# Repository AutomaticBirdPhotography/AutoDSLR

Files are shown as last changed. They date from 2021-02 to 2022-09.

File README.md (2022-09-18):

# AutoDSLR
Tracking pan-tilt DSLR head

På remote:  
```
sudo pip3 install -r requirements.txt
sudo pip3 install -U vidgear[core]
sudo apt install libgraphite2-3 libatspi2.0-0 libthai0 libxcb-shm0 libxcb-render0 libswscale5 librsvg2-2 libvorbisenc2 libavutil56 libzvbi0 libgsm1 libxinerama1 libxvidcore4 libsrt1.4-gnutls libswresample3 libatk1.0-0 libvorbisfile3 libogg0 libpangoft2-1.0-0 libpgm-5.3-0 libwayland-egl1 libharfbuzz0b libpango-1.0-0 libcairo2 libva-x11-2 libwayland-cursor0 libgfortran5 libxfixes3 libgme0 libxrender1 libvorbis0a libxi6 libudfread0 libspeex1 libwebpmux3 libsodium23 libdatrie1 libatk-bridge2.0-0 libxrandr2 libbluray2 libx264-160 libwavpack1 libxcomposite1 libpangocairo-1.0-0 libsoxr0 libshine3 libxkbcommon0 libvdpau1 libgtk-3-0 libopus0 librabbitmq4 libgdk-pixbuf-2.0-0 libavformat58 libmpg123-0 libxdamage1 libzmq5 libdav1d4 libopenmpt0 libatlas3-base libva2 libva-drm2 libxcursor1 libssh-gcrypt-4 libavcodec58 libaom0 libx265-192 libwayland-client0 libcairo-gobject2 libcodec2-0.9 libpixman-1-0 libdrm2 libsnappy1v5 libnorm1 libopenjp2-7 libtheora0 ocl-icd-libopencl1 libtwolame0 libvpx6 libepoxy0 libchromaprint1 libmp3lame0

#sudo apt-get install libatlas-base-dev libhdf5-dev libhdf5-serial-dev libatlas-base-dev libjasper-dev -y

cd /usr/share/applications
sudo cp python3.9.desktop remote.desktop
sudo nano remote.desktop
[Desktop Entry]
Encoding=UTF-8
Type=Application
Name=PanTilt Remote
Icon=/home/pi/Documents/AutoDSLR-main/icon.png
Terminal=true
Exec=/usr/bin/python3.9 /home/pi/Documents/AutoDSLR-main/pan_tilt_remote_v2.py
StartupNotify=false
Categories=Other

sudo cp remote.desktop shutdown.desktop
sudo nano shutdown.desktop
[Desktop Entry]
Encoding=UTF-8
Type=Application
Name=Shutdown
Icon=/home/pi/Documents/AutoDSLR-main/shutdown.png
Terminal=true
Exec=/usr/bin/python3.9 /home/pi/Documents/AutoDSLR-main/shutdown.py
StartupNotify=false
Categories=Other

cd /usr/local/lib/python3.9/dist-packages/vidgear/gears
sudo nano netgear.py
ctrl+"-"
681
endre fra 96 til 1
ctrl+"x"
y
enter

```

Problemer:

Koden for remote er egt. utdatert. Noe feil med "ved klikk" 10x for mye eller noe

Sliter med å få lock ved tracking

Krasjer med error "Broken pipe" stadig

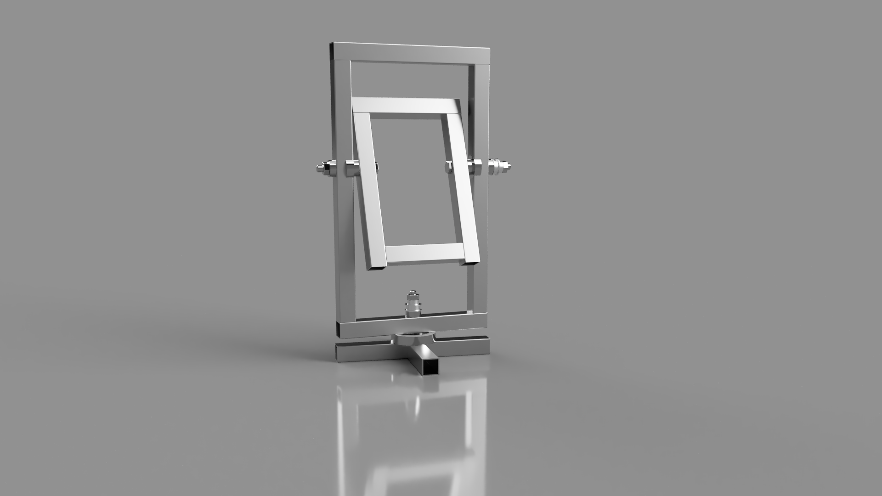
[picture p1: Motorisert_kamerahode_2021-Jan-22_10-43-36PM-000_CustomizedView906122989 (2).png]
The head


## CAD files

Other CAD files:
PCB_PanTilt v13.f3z
Pan tilt utstyrsboks v13.f3d

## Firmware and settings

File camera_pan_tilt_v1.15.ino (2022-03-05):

/*
      Author: Robert

      Version: 1.15.13
      Notes:
      Versjon 11 - Totalt endret hvordan stativet kjører; positiv y verdi kjører opp, positiv x verdi kjører høyre:
              0,10
               |
               |
      -10,0---0,0---10,0
               |
               |
              0,-10
      Data ved vanlig kjøring typ. joy: x, y, servo_x, servo_y
      Ved til point: p x_grader, y_grader

      Versjon 12 - Totalt endret hvordan servoen styrer etter data. Legger til grader hvert x millisekund, ettersom dette er det det ville blitt sendt på med python tidligere.
                .10 - satt tilbake hvordan servoen kan komme tilbake etter overstyring
                .13 - bevegelse i stativet etter "til klikk" løst ved å sette: innkommende = "0,0,0,0"
                .14 - endret hastigheten på servoen, sendes nå i verdier opp til 10
                .15 - lagt til pan og tilt offset for å kalibrere servokamera mot speilrefleks
                .17 - tune verdier ved align
      Versjon 1.xx - Med enablepins til motorene, potentiometer for initiell posisjon
                12
                  .01 - "b" skendes for å endre enable-pin, "f" for enable fokus
                13 - smoothing ved v- og hSpeed
                14 - servoer går til hjem rolig
                  .1 - med sending av steps
                15 - total endret hvordan enablepins fungerer, dette for å unngå "fantomtelling" av steps


      Python: pantilt.py -på stativet
*/
#include <Servo.h>
Servo panServo;
Servo tiltServo;
float posTilt = 0;
float posPan = 0;
float pan_offset = 12; //verdiene er etter de på kartet, negativ er venstre
float tilt_offset = -6; //negative verdier vil få den til å gå gå mot positive verdier
float OldPosTilt = 90 + tilt_offset;
float OldPosPan = 90 + pan_offset;
int tiltLimit = 85;
int i = 1;
int n = 1;
int gjenMove = 0;
unsigned long timeNow = 0;
int period = 90; //oppdateringsfrekvensen på servoen

#include <AccelStepper.h>

const int vertikalDirPin = 7;
const int vertikalStepPin = 6;
const int enablePin = 2;
String vIn = "0";
String OvIn = "0";
int vSpeed = 0;
float vSpeedSmooth = 0;
float vSpeedPrev = 0;   //brukes for smoothing
int vPosPrev = 0;      //brukes for sending av steps til serial
#define motorInterfaceType 1
AccelStepper vertikal(motorInterfaceType, vertikalStepPin, vertikalDirPin);

const int horisontalDirPin = 8;
const int horisontalStepPin = 9;
String hIn = "0";
String OhIn = "0";
int hSpeed = 0;
float hSpeedSmooth = 0;
float hSpeedPrev = 0;   //brukes for smoothing
int hPosPrev = 0;      //brukes for sending av steps til serial
#define motorInterfaceType 1
AccelStepper horisontal(motorInterfaceType, horisontalStepPin, horisontalDirPin);

const int fokusEnablePin = 12;
/*
  const int fokusDirPin = 3;
  const int fokusStepPin = 4;

  String fIn = "0";
  String OfIn = "0";
  int fSpeed = 0;
  #define motorInterfaceType 1
  AccelStepper fokus(motorInterfaceType, fokusStepPin, fokusDirPin);
*/
const int maxUp = 650;
const int maxDown = -350;       //hvor langt motoren kan gå før det er fare for at kameraet treffer rammen
String innkommende;
bool enable = false;
bool fokusEnable = false;

#define pot A7
unsigned long potVerdi = 0;

void setup() {
  pinMode(pot, INPUT);

  digitalWrite(fokusEnablePin, HIGH);

  panServo.attach(11);
  tiltServo.attach(10);
  panServo.write(90 + pan_offset);
  tiltServo.write(90 + tilt_offset);



  vertikal.setMaxSpeed(200);
  vertikal.setCurrentPosition(0);
  vertikal.setAcceleration(5000);
  vertikal.setEnablePin(enablePin);
  vertikal.setPinsInverted(false, false, true);   //enable når pinnen er LOW
  horisontal.setMaxSpeed(200);
  horisontal.setAcceleration(5000);
  horisontal.setCurrentPosition(0);
  horisontal.setEnablePin(enablePin);
  horisontal.setPinsInverted(false, false, true);
  //fokus.setMaxSpeed(100);
  //fokus.setAcceleration(300);
  //fokus.setCurrentPosition(0);
  Serial.begin(115200);
  Serial.setTimeout(15);

  //skrur seg på, så kjører til hjem
  vertikal.enableOutputs();     //vertikal og horisontal har samme enablepin; så ubetydelig hvem som er valgt
  for (int i = 0; i < 500; i++) {
    potVerdi += analogRead(pot);
  }
  int homing = map((potVerdi / 500), 838, 596, 500, -500); //verdier kalibrert tidligere
  potVerdi = 0;
  vertikal.setSpeed(50);
  vertikal.move(homing);
  vertikal.runToPosition();
  vertikal.setCurrentPosition(0);
  vertikal.setSpeed(200);
  vertikal.disableOutputs();
  // motorene skal ikke være på i starten

}

void loop() {
  if (Serial.available() > 0) {
    innkommende = Serial.readStringUntil('\n');
  }
  if (innkommende[0] != 'h' && innkommende[0] != 'a' && innkommende[0] != 'p' && innkommende[0] != 'b' && innkommende[0] != 'f') {  //må ikke være noen av disse verdiene
    int komma = innkommende.indexOf(',');
    int andrekomma = innkommende.indexOf(',', komma + 1);
    int tredjekomma = innkommende.indexOf(',', andrekomma + 1);
    int fjerdekomma = innkommende.indexOf(',', tredjekomma + 1);
    String hIn = innkommende.substring(0, komma);
    String vIn = innkommende.substring(komma + 1, andrekomma);
    String AxisPan = innkommende.substring(andrekomma + 1, tredjekomma);
    String AxisTilt = innkommende.substring(tredjekomma + 1, fjerdekomma);
    float posTilt = AxisTilt.toFloat() / -10;
    if (posTilt < 8.0/-10.0) posTilt = 8.0/-10.0;           //må endres i samsvar med kontroller (-10.0 (.0 for float) må endres etter hva man deler på ved Axis-), forhindrer feildata!
    else if (posTilt > 8.0/10.0) posTilt = 8.0/10.0;
    
    float posPan = AxisPan.toFloat() / -10;
    if (posPan < 8.0/-10.0) posPan = 8.0/-10.0;
    else if (posPan > 8.0/10.0) posPan = 8.0/10.0;

    if (millis() >= timeNow + period) {
      timeNow = millis();
      panServo.write(OldPosPan + posPan);
      if (OldPosPan >= 180) {
        if (posPan < 0) {
          OldPosPan += posPan;
        }
      }
      else if (OldPosPan <= 0) {
        if (posPan > 0) {
          OldPosPan += posPan;
        }
      }
      else {
        OldPosPan += posPan;
      }
      
      if (OldPosPan < 75 || OldPosPan > 115) {
        if (OldPosTilt > tiltLimit) {      //0 Er rett opp, 180 rett ned; lavere verdi: høyere opp
          tiltServo.write(tiltLimit);
          OldPosTilt = tiltLimit;
        }
        if (OldPosTilt + posTilt > tiltLimit) {
          tiltServo.write(tiltLimit);
          OldPosTilt = tiltLimit;
        }
        else {
          tiltServo.write(OldPosTilt + posTilt);
        }

      }
      else {
        tiltServo.write(OldPosTilt + posTilt);
      }

      if (OldPosTilt >= 120) {
        if (posTilt < 0) {
          OldPosTilt += posTilt;
        }
      }
      else if (OldPosTilt <= 60) {
        if (posTilt > 0) {
          OldPosTilt += posTilt;
        }
      }
      else {
        OldPosTilt += posTilt;
      }
    }
    //-----------------------------------
    if (vIn != OvIn) {
      vSpeed = -vIn.toInt();
    }

    if (hIn != OhIn) {
      hSpeed = hIn.toInt();
    }


    OhIn = hIn;
    OvIn = vIn;
  }



  if (innkommende[0] == 'h' && enable) { //skal ikke bli sann om motorene ikke er på
    if (i == 1) {
      int x = panServo.read();
      if (x < 90 + pan_offset) {
        for (int i = x; i <= 90 + pan_offset; i++) {
          panServo.write(i);
          delay(50);
        }
      }
      else if (x > 90 + pan_offset) {
        for (int i = x; i >= 90 + pan_offset; i--) {
          panServo.write(i);
          delay(50);
        }
      }

      //------tilt--
      x = tiltServo.read();
      if (x < 90 + tilt_offset) {
        for (int i = x; i <= 90 + tilt_offset; i++) {
          tiltServo.write(i);
          delay(50);
        }
      }
      else if (x > 90 + tilt_offset) {
        for (int i = x; i >= 90 + tilt_offset; i--) {
          tiltServo.write(i);
          delay(50);
        }
      }

      for (int i = 0; i < 500; i++) {
        potVerdi += analogRead(pot);
      }
      int homing = map((potVerdi / 500), 838, 596, 500, -500); //verdier kalibrert tidligere
      potVerdi = 0;
      vertikal.move(homing);
      vertikal.setSpeed(70);
      while (vertikal.distanceToGo() != 0) {
        vertikal.runSpeedToPosition();
      }
      vertikal.setCurrentPosition(0);
      i = 2;
      OldPosPan = 90 + pan_offset;
      OldPosTilt = 90 + tilt_offset;
    }
    Serial.println("h");
  }
  else if (innkommende[0] == 'a' && enable) {
    if (n == 1) {
      //nema 17 : 200 steps pr rev. *16(microstepping) *1,8(36/20(tannhjul))=5760 -> 1deg = 16steps (5760/360)
      float horisontalAlignPos = (OldPosPan - (90 + pan_offset)) * 15; //kjører litt for langt
      float vertikalAlignPos = (OldPosTilt - (90 + tilt_offset)) * 16;
      if (vertikalAlignPos > maxUp) {
        vertikalAlignPos = maxUp;
      }
      else if (vertikalAlignPos < maxDown) {
        vertikalAlignPos = maxDown;
      }

      horisontal.move(horisontalAlignPos * -1);
      int totalMove = horisontal.distanceToGo();
      gjenMove = totalMove;

      vertikal.moveTo(vertikalAlignPos);

      while ((horisontal.distanceToGo() != 0 && vertikal.distanceToGo() != 0) || (horisontal.distanceToGo() != 0 || vertikal.distanceToGo() != 0)) {
        gjenMove = horisontal.distanceToGo();
        float alignPanServo = map(gjenMove, 0, totalMove, 90 + pan_offset, OldPosPan);
        panServo.write(alignPanServo);
        horisontal.setSpeed(80);
        horisontal.runSpeedToPosition();
        vertikal.setSpeed(80);
        vertikal.runSpeedToPosition();
      }
      n = 2;
      OldPosPan = 90 + pan_offset;
      innkommende = "0,0,0,0";
      Serial.println("a");
    }
  }
  else if (innkommende[0] == 'b') {
    enable = !enable;
    if (enable) {
      vertikal.enableOutputs();
    }
    if (enable == false) {
      vertikal.disableOutputs();
    }
    innkommende = "0,0,0,0";
  }
  else if (innkommende[0] == 'f') {
    fokusEnable = !fokusEnable;
    if (fokusEnable) {
      digitalWrite(fokusEnablePin, LOW);
    }
    if (fokusEnable == false) {
      digitalWrite(fokusEnablePin, HIGH);
    }

  }
  else if (innkommende[0] == 'p' && enable) {
    innkommende.remove(0, 1); //fjerner første bokstav, som er p
    int komma = innkommende.indexOf(',');
    String hGrader = innkommende.substring(0, komma);
    //Serial.println(vGrader);
    String vGrader = innkommende.substring(komma + 1);
    float fvGrader = vGrader.toFloat();
    float fhGrader = hGrader.toFloat();
    float fvSteps = fvGrader * -16;
    float fhSteps = fhGrader * 16;
    int vSteps = round(fvSteps);
    if (vSteps + vertikal.currentPosition() > maxUp) {
      vSteps = maxUp - vertikal.currentPosition();    //hvis maxUp er 300 og currentPosition er 301 blir vSteps -1, slik at den kjører tilbake dit den skal :)
    }
    else if (vSteps + vertikal.currentPosition() < maxDown) {
      vSteps = maxDown - vertikal.currentPosition();
    }
    int hSteps = round(fhSteps);
    vertikal.move(vSteps);
    horisontal.move(hSteps);
    while ((horisontal.distanceToGo() != 0 && vertikal.distanceToGo() != 0) || (horisontal.distanceToGo() != 0 || vertikal.distanceToGo() != 0)) {
      horisontal.setSpeed(100);
      horisontal.runSpeedToPosition();
      vertikal.setSpeed(100);
      vertikal.runSpeedToPosition();
    }
    hSpeed = 0;
    vSpeed = 0;
    innkommende = "0,0,0,0";
    Serial.println("p");
  }
  else {
    if (enable) {
      vSpeedSmooth = (vSpeed * 0.005) + (vSpeedPrev * 0.995);
      vSpeedPrev = vSpeedSmooth;

      //Serial.println(vertikal.currentPosition());
      if (vertikal.currentPosition() > maxUp) {
        if (vSpeed < 0) {
          vertikal.setSpeed(vSpeedSmooth);
          vertikal.runSpeed();
        }
      }
      else if (vertikal.currentPosition() < maxDown) {
        if (vSpeed > 0) {
          vertikal.setSpeed(vSpeedSmooth);
          vertikal.runSpeed();
        }
      }
      else {
        vertikal.setSpeed(vSpeedSmooth);
        vertikal.runSpeed();
      }
      hSpeedSmooth = (hSpeed * 0.005) + (hSpeedPrev * 0.995);
      hSpeedPrev = hSpeedSmooth;
      horisontal.setSpeed(hSpeedSmooth);
      horisontal.runSpeed();
      //fokus.setSpeed(fSpeed);
      //fokus.run();
      i = 1;
      n = 1;
    }
  }
  if ((horisontal.currentPosition() != hPosPrev) || (vertikal.currentPosition() != vPosPrev)) {
    //Serial.println("c" + (String)horisontal.currentPosition() + "," + (String)vertikal.currentPosition());
    hPosPrev = horisontal.currentPosition();
    vPosPrev = vertikal.currentPosition();
  }
}

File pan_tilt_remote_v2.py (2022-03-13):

"""
!DETTE ER HOVEDVERSJONEN AV PROGRAMMET. BRUKES AV REMOTE-SHORTCUT!
versjon 2.9.7
"""

import PySimpleGUI as sg
import cv2, time, pygame, math, socket, threading
import numpy as np
from vidgear.gears import NetGear

'''
Notes:
Dataen sendes slik: 
s.send("j{"lengden på bufferen"}{:.0f},{:.0f},{:.0f},{:.0f}".format(hSpeed, vSpeed, PanServo, TiltServo).encode())
'''

#-------------------------Starte ulike resurrser--------------------------------------------------
s = socket.socket(socket.AF_INET, socket.SOCK_STREAM)
retries = 15

while s.connect_ex(("192.168.4.1", 65432)) != 0:
    print(f"Kunne ikke koble til! prøver {retries} ganger til")
    retries -= 1
    if retries <= 0:
        print("Klarte ikke etablere kontakt med PanTilt!")
        exit()
    time.sleep(5)
print("Koblet til PanTilt")

options = {
    "request_timeout": 10,
    "max_retries": 20,
}
dslrClient = NetGear("192.168.4.4", 2345, receive_mode=True, pattern = 0, **options)
camClient = NetGear("192.168.4.4", 1234, receive_mode=True, pattern = 0, **options)


pygame.init()
time.sleep(1)
joystick = pygame.joystick.Joystick(0)
joystick.init()
print("Laster...")
time.sleep(0.5)

#----------------Variabler------------------------------------------------------------------
dslrScale = 95
dslrScaleFull = 130
camScale = 145
#halverer størrelsen på bildet, graphkordinatene må dobles | bildet ganges med scale/100, kordinatene deles med scale/100
#dobler størrelsen, halverer kordinatene
dslrFrameOrig = np.full((480, 640), 255, dtype='uint8') #dslrFrame = dslrClient.recv()
dslrFrame = cv2.resize(dslrFrameOrig, (int(dslrFrameOrig.shape[1]*(dslrScale/100)), int(dslrFrameOrig.shape[0]*(dslrScale/100))), interpolation = cv2.INTER_AREA)
camFrameOrig = np.full((320, 240), 255, dtype='uint8') #camFrame = camClient.recv()
camFrame = cv2.resize(camFrameOrig, (int(camFrameOrig.shape[1]*((camScale)/100)), int(camFrameOrig.shape[0]*(camScale/100))), interpolation = cv2.INTER_AREA)
dslrBytes = cv2.imencode('.png', dslrFrame)[1].tobytes()
camBytes = cv2.imencode('.png', camFrame)[1].tobytes()

h_sensor = 23.5
focal_lenght = 500
h_angle = 2 * math.atan(float(h_sensor) / (2 * int(focal_lenght))) * (360 / (2 * math.pi))
degrees_per_pixel = h_angle/dslrFrame.shape[1]


joy = True
tracking = False
a_id = None

dragging = False
start_point = end_point = prior_rect = None
update = False
point = False
stop = False
encode = True
old_event = '__TIMEOUT__'
joyInput = False
down = False

rect_x = 0
rect_y = 0
rect_width = 0
rect_height = 0
bbox = (0,0,0,0)

steps = (0,0)

Old_hSpeed = 0
Old_vSpeed = 0
Old_PanServo = 0
Old_TiltServo = 0
first_value = True
enable = False
view_dslr_layout = False

#---------------------GUI-----------------------------------------------------------------
w, h = sg.Window.get_screen_size()
sg.theme('Black')
state_button = sg.Button('X', size=(2, 3), font='Any 15', button_color=('white', 'red'))
track_button = sg.Button('Start følgning', size=(12, 3), font='Helvetica 15', button_color=('black', 'white'))
point_button = sg.Button('Start klikk', size=(10, 3), font='Helvetica 15', button_color=('black', 'white'))
joy_button = sg.Button('Stopp joy', size=(10, 3), font='Helvetica 15', button_color=('white', 'blue'))
align_button = sg.Button('+', size=(3, 3), font='Helvetica 15')
home_button = sg.Button('Hjem', size=(10, 3), font='Helvetica 15')
focal_button = sg.Button('F', size=(3, 3), font='Helvetica 15')
enable_button = sg.Button('OFF', size=(4, 3), font='Helvetica 15', button_color=('white', 'red'))
layout_column = [[sg.Image(filename='', key='web'),
                sg.Image(filename='', key='dslr'), sg.Graph(canvas_size=(dslrFrame.shape[1], dslrFrame.shape[0]), graph_bottom_left=(0, dslrFrame.shape[0]), graph_top_right=(dslrFrame.shape[1], 0), key="-DSLR-", change_submits=True, background_color='lightblue', drag_submits=True),],
                [focal_button, home_button, align_button, track_button, joy_button, point_button, enable_button, state_button]]
layout_dslr = [[sg.Image(filename='', key='dslr_full'), sg.Button('Ut', size=(6,2), font='Helvetica 15', button_color=('white', 'red'))]]

layout_focal_input = [[sg.Text(size=(1,18))],[sg.Text(f'Brennvidde: {focal_lenght}mm, {round(h_angle, 2)}', key='tekst', size=(22,1), font='Helvetica 28'), sg.Combo(['50','70','200','500','750'], default_value='500', key='brennvidde', font='Helvetica 35')], [sg.Button('OK', font='Helvetica 28', bind_return_key=True)]]

layout = [[sg.Text(justification=('right'), key='battery')], [sg.Column(layout_column, justification='center', element_justification='center', key='BASE'), sg.Column(layout_dslr, justification='center', element_justification='center', key='FULL_DSLR', visible=False), sg.Column(layout_focal_input, justification='center', element_justification='center', key='FOCAL_INPUT', visible=False)]]

window = sg.Window('En', layout, no_titlebar=True, location=(0, 0), size=(w, h)).Finalize()#sg.Window('En', layout, no_titlebar = True, keep_on_top = True, location=(0, 0), size=(w, h)).Finalize()
graph = window["-DSLR-"]
window.TKroot["cursor"] = "none"


#-------------Funksjoner----------------------------
def speed(x):
    offset = 20 #dødgang på joy
    if x > offset:
        return 1.25*x-25
    elif x < -offset:
        return 1.25*x+25
    else:
        return 0
        

def update_focal():
    global h_angle
    inn = values['brennvidde']
    h_angle = 2 * math.atan(float(h_sensor) / (2 * int(inn))) * (360 / (2 * math.pi))
    degrees_per_pixel = h_angle/dslrFrame.shape[1]
    h_angle = round(h_angle, 2)
    window['tekst']. update("Brennvidde: " + values['brennvidde'] + f"mm, {h_angle}")

def battery():
    percentage = 10
    window['battery'].update(f'{percentage}%')
battery()

def recieve_steps():
    global steps
    try:
        while encode:
            steps = s.recv(32)
    
    except Exception as e:
        print("!!!!!!!!!!!ERROR!!!!!!!!!!")
        print(e)

threading._start_new_thread(recieve_steps, ());

def roi(start_point, end_point):
    global rect_x, rect_y, rect_width, rect_height, bbox
    if start_point[0] <= end_point[0]:
        rect_x = start_point[0]
        rect_width = end_point[0]-start_point[0]
    else:
        rect_x = end_point[0]
        rect_width = start_point[0]-end_point[0]
    
    if start_point[1] <= end_point[1]:
        rect_y = start_point[1]
        rect_height = end_point[1]-start_point[1]
    else:
        rect_y = end_point[1]
        rect_height = start_point[1]-end_point[1]
    
    bbox = (int(rect_x/(dslrScale/100)), int(rect_y/(dslrScale/100)), int(rect_width/(dslrScale/100)), int(rect_height/(dslrScale/100)))
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

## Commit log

2021-03-24 Create camera pan tilt laptop.py
2021-03-24 Update camera pan tilt laptop.py
